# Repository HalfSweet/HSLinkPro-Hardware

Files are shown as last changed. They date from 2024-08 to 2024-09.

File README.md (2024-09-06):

# HSLinkPro

## 本仓库不再更新！！

新的参考设计: <https://github.com/cherry-embedded/CherryDAP/tree/master/projects/HSLink-Pro/hardware>

HSLink Pro是一款基于HPM5301系列MCU的调试器。最高SWD/JTAG通信速率可达80M，并且拥有一路USB转串口，并带有DTR与RTS的输出，方便某些串口下载的MCU应用。

HSLink Pro软件参考<https://github.com/cherry-embedded/CherryDAP>。

## KiCAD 版本

使用8.0以上版本的KiCAD打开。

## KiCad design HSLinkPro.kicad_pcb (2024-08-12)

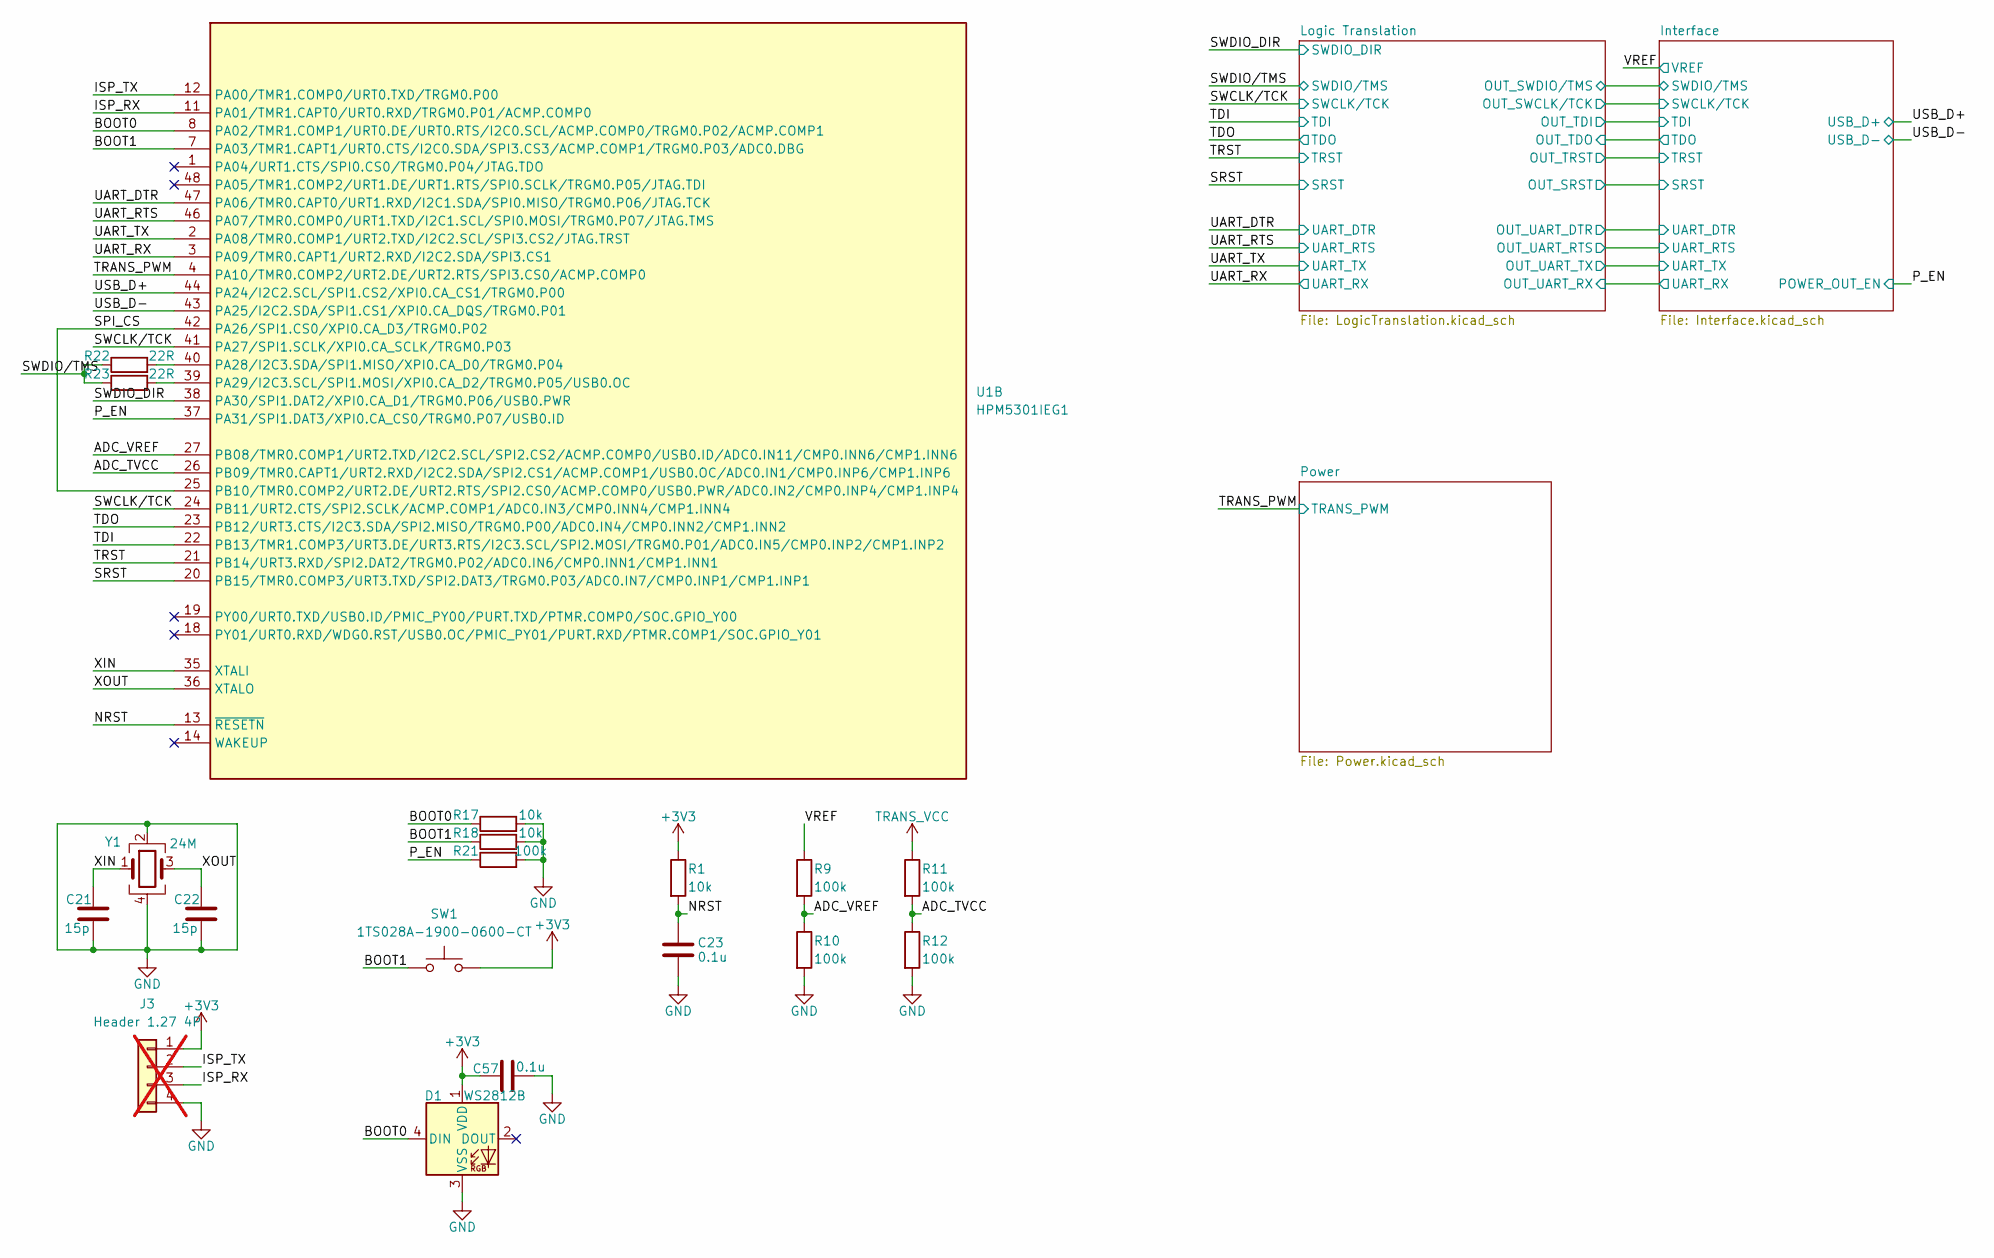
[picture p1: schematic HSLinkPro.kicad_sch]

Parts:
C21, C22: 15p; C_0402_1005Metric
C23, C57: 0.1u; C_0402_1005Metric
D1: WS2812B; LED_WS2812_0807
J3: Header 1.27 4P; PinHeader_1x04_P1.27mm_Vertical; not fitted
R1, R17, R18: 10k; R_0402_1005Metric
R9, R10, R11, R12, R21: 100k; R_0402_1005Metric
R22, R23: 22R; R_0402_1005Metric
SW1: 1TS028A-1900-0600-CT; SW-SMD_4P-L2.8-W1.9-P1.20-LS3.0_1TS028A
U1: HPM5301IEG1; QFN-48-1EP_6x6mm_P0.4mm_EP4.2x4.2mm
Y1: 24M; Crystal_SMD_2016-4Pin_2.0x1.6mm

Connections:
+3V3: C57.1, D1.1 (VDD), J3.1, R1.1, SW1.2; also elsewhere on the board
/ADC_TVCC: R11.2, R12.1, U1.26 (PB09/TMR0.CAPT1/URT2.RXD/I2C2.SDA/SPI2.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)
/ADC_VREF: R9.2, R10.1, U1.27 (PB08/TMR0.COMP1/URT2.TXD/I2C2.SCL/SPI2.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)
/BOOT0: D1.4 (DIN), R17.1, U1.8 (PA02/TMR1.COMP1/URT0.DE/URT0.RTS/I2C0.S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)
/BOOT1: R18.1, SW1.1, U1.7 (PA03/TMR1.CAPT1/URT0.CTS/I2C0.SDA/SPI3.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)
/ISP_RX: J3.3, U1.11 (PA01/TMR1.CAPT0/URT0.RXD/TRGM0.P01/ACMP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)
/ISP_TX: J3.2, U1.12 (PA00/TMR1.COMP0/URT0.TXD/TRGM0.P00)
/NRST: C23.1, R1.2, U1.13 (~RESETN)
/P_EN: R21.1, U1.37 (PA31/SPI1.DAT3/XPI0.CA_CS0/TRGM0.P07/US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); also elsewhere on the board
/SPI_CS: U1.25 (PB10/TMR0.COMP2/URT2.DE/URT2.RTS/SPI2.C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), U1.42 (PA26/SPI1.CS0/XPI0.CA_D3/TRGM0.P02)
/SRST: U1.20 (PB15/TMR0.COMP3/URT3.TXD/SPI2.DAT3/TRGM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); also elsewhere on the board
/SWCLK/TCK: U1.24 (PB11/URT2.CTS/SPI2.SCLK/ACMP.COMP1/ADC0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), U1.41 (PA27/SPI1.SCLK/XPI0.CA_SCLK/TRGM0.P03); also elsewhere on the board
/SWDIO_DIR: U1.38 (PA30/SPI1.DAT2/XPI0.CA_D1/TRGM0.P06/USB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); also elsewhere on the board
/SWDIO/TMS: R22.1, R23.1; also elsewhere on the board
/TDI: U1.22 (PB13/TMR1.COMP3/URT3.DE/URT3.RTS/I2C3.S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); also elsewhere on the board
/TDO: U1.23 (PB12/URT3.CTS/I2C3.SDA/SPI2.MISO/TRGM0.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); also elsewhere on the board
/TRANS_PWM: U1.4 (PA10/TMR0.COMP2/URT2.DE/URT2.RTS/SPI3.C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); also elsewhere on the board
/TRST: U1.21 (PB14/URT3.RXD/SPI2.DAT2/TRGM0.P02/ADC0.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); also elsewhere on the board
/UART_DTR: U1.47 (PA06/TMR0.CAPT0/URT1.RXD/I2C1.SDA/SPI0.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); also elsewhere on the board
/UART_RTS: U1.46 (PA07/TMR0.COMP0/URT1.TXD/I2C1.SCL/SPI0.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); also elsewhere on the board
/UART_RX: U1.3 (PA09/TMR0.CAPT1/URT2.RXD/I2C2.SDA/SPI3.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); also elsewhere on the board
/UART_TX: U1.2 (PA08/TMR0.COMP1/URT2.TXD/I2C2.SCL/SPI3.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); also elsewhere on the board
/USB_D+: U1.44 (PA24/I2C2.SCL/SPI1.CS2/XPI0.CA_CS1/TRGM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); also elsewhere on the board
/USB_D-: U1.43 (PA25/I2C2.SDA/SPI1.CS1/XPI0.CA_DQS/TRGM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); also elsewhere on the board
/VREF: R9.1; also elsewhere on the board
/XIN: C21.1, U1.35 (XTALI), Y1.1
/XOUT: C22.1, U1.36 (XTALO), Y1.3
GND: C21.2, C22.2, C23.2, C57.2, D1.3 (VSS), J3.4, R10.2, R12.2, R17.2, R18.2, R21.2, Y1.2, Y1.4; also elsewhere on the board
unnamed: R22.2, U1.40 (PA28/I2C3.SDA/SPI1.MISO/XPI0.CA_D0/TRGM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)
unnamed: R23.2, U1.39 (PA29/I2C3.SCL/SPI1.MOSI/XPI0.CA_D2/TRGM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)
TRANS_VCC: R11.1; also elsewhere on the board

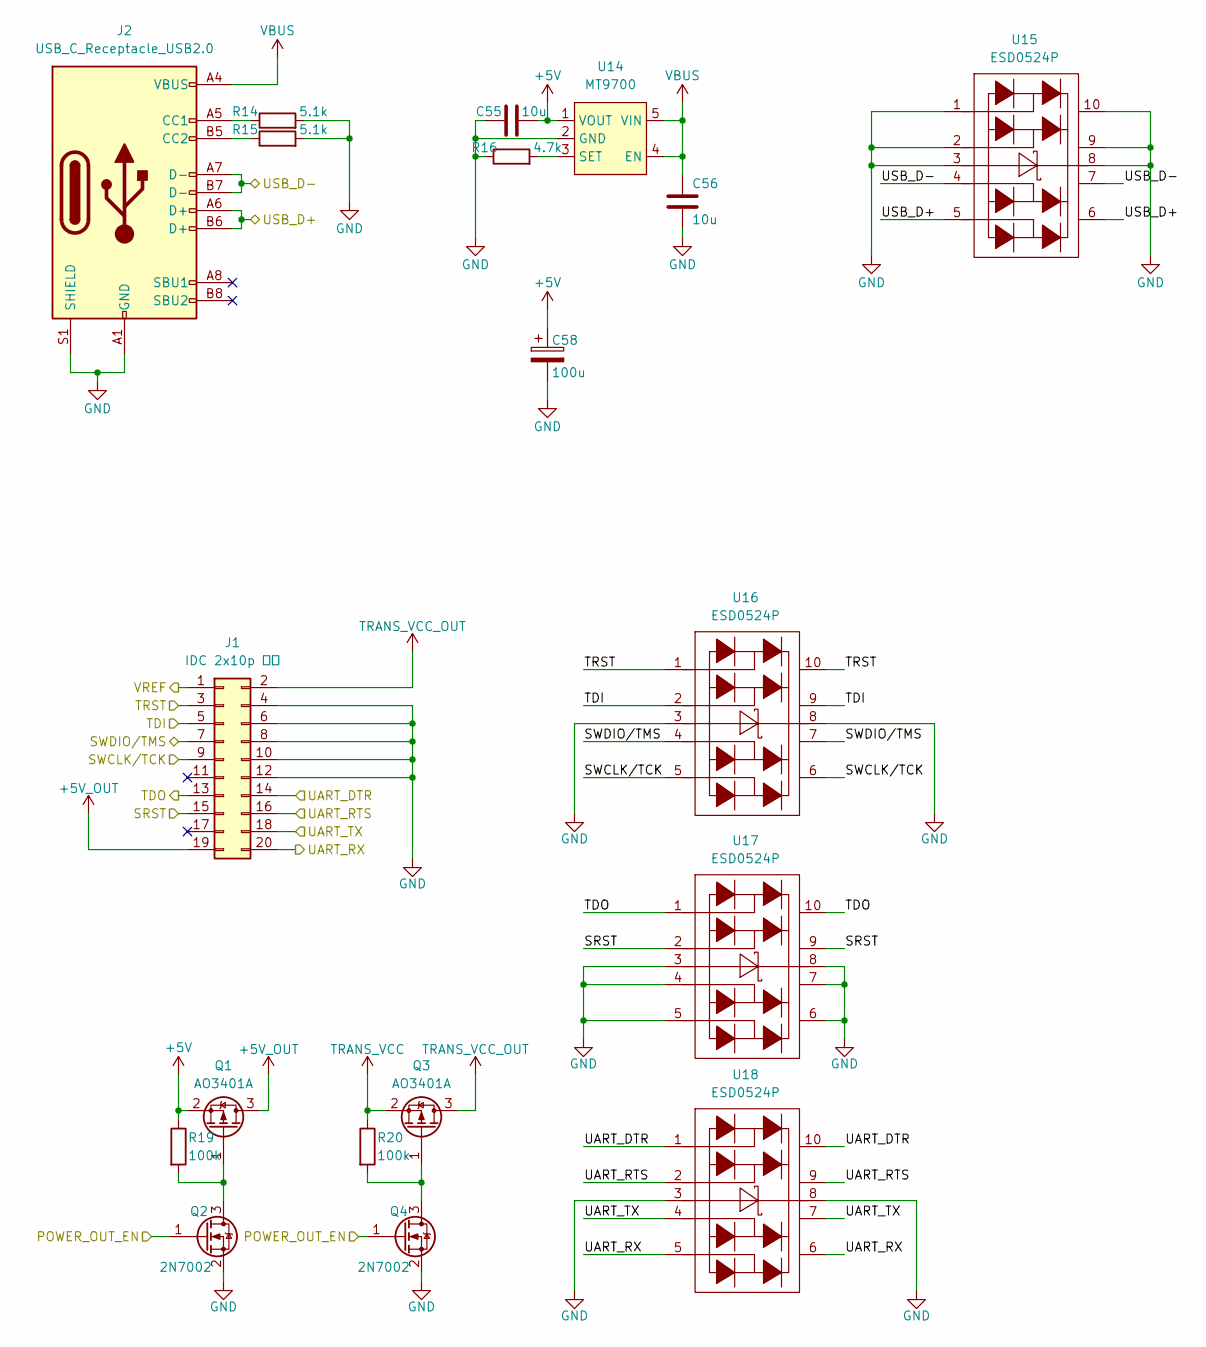
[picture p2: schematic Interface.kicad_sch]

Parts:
C55, C56: 10u; C_0603_1608Metric
C58: 100u; CP_EIA-3528-21_Kemet-B
J1: IDC 2x10p 夹板; Conn_02x10_IDC_SMD
J2: USB_C_Receptacle_USB2.0; USB-C-SMD_CX90M-16P
Q1, Q3: AO3401A; SOT-23
Q2, Q4: 2N7002; SOT-323_SC-70
R14, R15: 5.1k; R_0402_1005Metric
R16: 4.7k; R_0402_1005Metric
R19, R20: 100k; R_0402_1005Metric
U14: MT9700; SOT-23-5
U15, U16, U17, U18: ESD0524P; DFN-10_L2.5-W1.0-P0.50-BL-A

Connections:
+5V: C55.2, C58.1, Q1.2 (S), R19.1, U14.1 (VOUT); also elsewhere on the board
+5V_OUT: J1.19, Q1.3 (D)
/Interface /<NO NET>: J1.5, U16.2, U16.9; also elsewhere on the board
/Interface /SRST: J1.15, U17.2, U17.9; also elsewhere on the board
/Interface /SWCLK/TCK: J1.9, U16.5, U16.6; also elsewhere on the board
/Interface /SWDIO/TMS: J1.7, U16.4, U16.7; also elsewhere on the board
/Interface /TDO: J1.13, U17.1, U17.10; also elsewhere on the board
/Interface /TRST: J1.3, U16.1, U16.10; also elsewhere on the board
/Interface /UART_DTR: J1.14, U18.1, U18.10; also elsewhere on the board
/Interface /UART_RTS: J1.16, U18.2, U18.9; also elsewhere on the board
/Interface /UART_RX: J1.20, U18.5, U18.6; also elsewhere on the board
/Interface /UART_TX: J1.18, U18.4, U18.7; also elsewhere on the board
/P_EN: Q2.1 (G), Q4.1 (G); also elsewhere on the board
/USB_D+: J2.A6 (D+), J2.B6 (D+), U15.5, U15.6; also elsewhere on the board
/USB_D-: J2.A7 (D-), J2.B7 (D-), U15.4, U15.7; also elsewhere on the board
/VREF: J1.1; also elsewhere on the board
GND: C55.1, C56.2, C58.2, J1.4, J1.6, J1.8, J1.10, J1.12, J2.A1 (GND), J2.A12 (GND), J2.B1 (GND), J2.B12 (GND), J2.S1 (SHIELD), Q2.2 (S), Q4.2 (S), R14.2, R15.2, R16.1, U14.2 (GND), U15.1, U15.2, U15.3, U15.8, U15.9, U15.10, U16.3, U16.8, U17.3, U17.4, U17.5, U17.6, U17.7, U17.8, U18.3, U18.8; also elsewhere on the board
unnamed: J2.A5 (CC1), R14.1
unnamed: J2.B5 (CC2), R15.1
unnamed: Q1.1 (G), Q2.3 (D), R19.2
unnamed: Q3.1 (G), Q4.3 (D), R20.2
unnamed: R16.2, U14.3 (SET)
TRANS_VCC: Q3.2 (S), R20.1; also elsewhere on the board
TRANS_VCC_OUT: J1.2, Q3.3 (D)
VBUS: C56.1, J2.A4 (VBUS), J2.A9 (VBUS), J2.B4 (VBUS), J2.B9 (VBUS), U14.4 (EN), U14.5 (VIN)

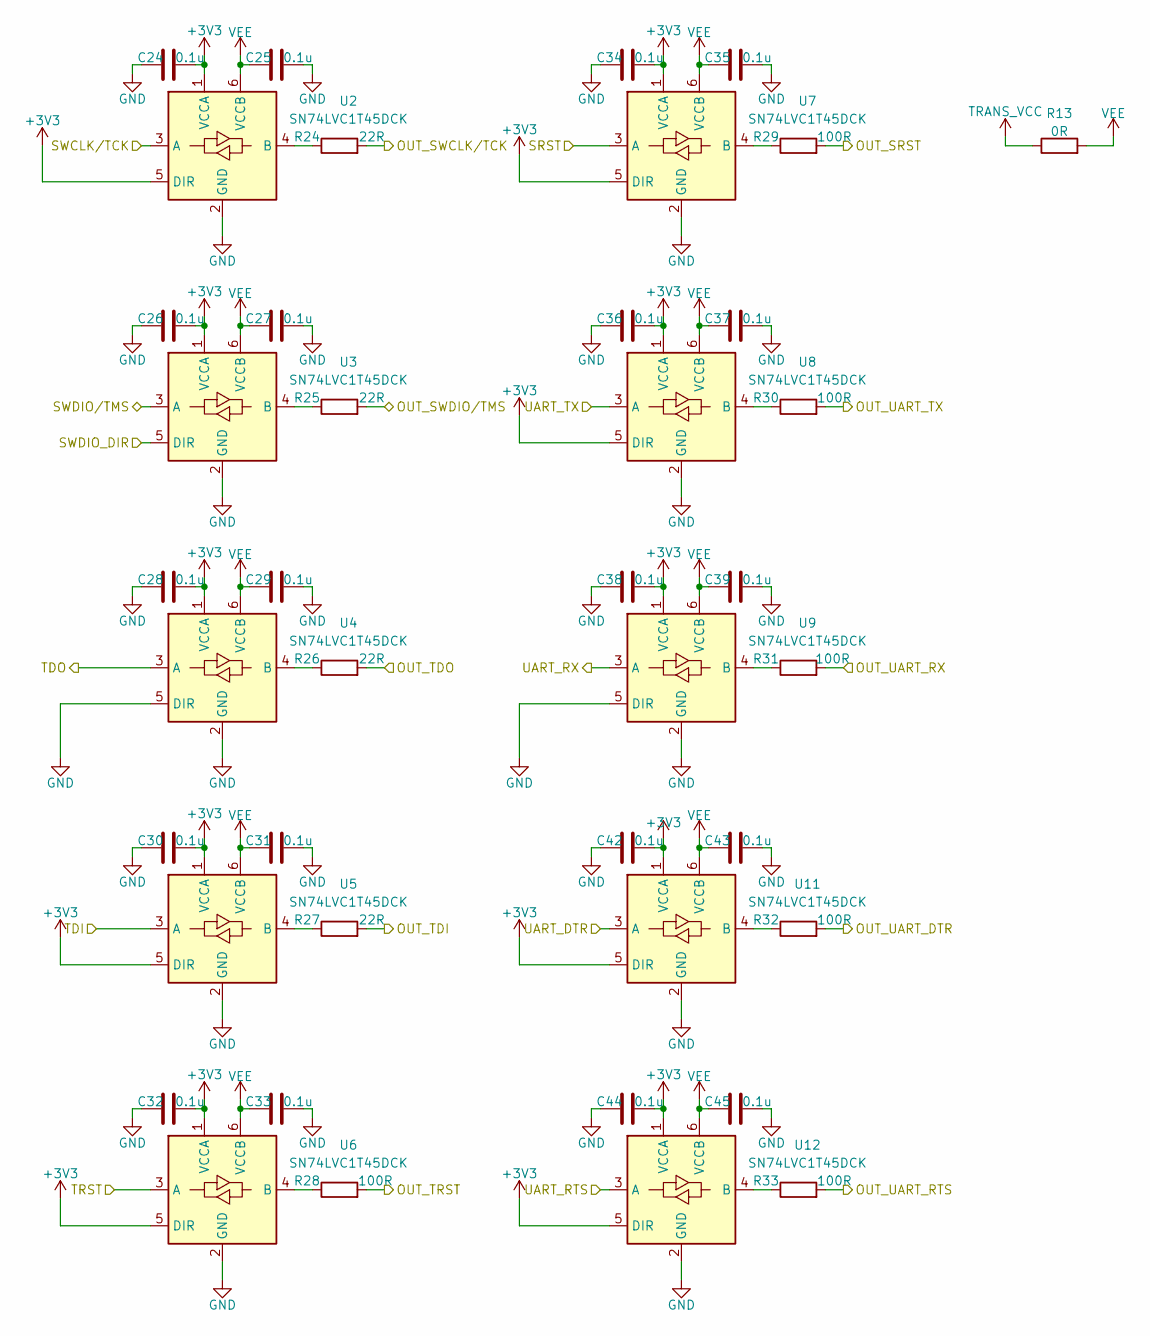
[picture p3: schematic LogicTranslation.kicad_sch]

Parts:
C24, C25, C26, C27, C28, C29, C30, C31, C32, C33, C34, C35, C36, C37, C38, C39, C42, C43, C44, C45: 0.1u; C_0402_1005Metric
R13: 0R; R_0603_1608Metric
R24, R25, R26, R27: 22R; R_0402_1005Metric
R28, R29, R30, R31, R32, R33: 100R; R_0402_1005Metric
U2, U3, U4, U5, U6, U7, U8, U9, U11, U12: SN74LVC1T45DCK; SOT-363_SC-70-6

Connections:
+3V3: C24.2, C26.2, C28.2, C30.2, C32.2, C34.2, C36.2, C38.2, C42.2, C44.2, U2.1 (VCCA), U2.5 (DIR), U3.1 (VCCA), U4.1 (VCCA), U5.1 (VCCA), U5.5 (DIR), U6.1 (VCCA), U6.5 (DIR), U7.1 (VCCA), U7.5 (DIR), U8.1 (VCCA), U8.5 (DIR), U9.1 (VCCA), U11.1 (VCCA), U11.5 (DIR), U12.1 (VCCA), U12.5 (DIR); also elsewhere on the board
/Interface /<NO NET>: R27.2; also elsewhere on the board
/Interface /SRST: R29.2; also elsewhere on the board
/Interface /SWCLK/TCK: R24.2; also elsewhere on the board
/Interface /SWDIO/TMS: R25.2; also elsewhere on the board
/Interface /TDO: R26.2; also elsewhere on the board
/Interface /TRST: R28.2; also elsewhere on the board
/Interface /UART_DTR: R32.2; also elsewhere on the board
/Interface /UART_RTS: R33.2; also elsewhere on the board
/Interface /UART_RX: R31.2; also elsewhere on the board
/Interface /UART_TX: R30.2; also elsewhere on the board
/SRST: U7.3 (A); also elsewhere on the board
/SWCLK/TCK: U2.3 (A); also elsewhere on the board
/SWDIO_DIR: U3.5 (DIR); also elsewhere on the board
/SWDIO/TMS: U3.3 (A); also elsewhere on the board
/TDI: U5.3 (A); also elsewhere on the board
/TDO: U4.3 (A); also elsewhere on the board
/TRST: U6.3 (A); also elsewhere on the board
/UART_DTR: U11.3 (A); also elsewhere on the board
/UART_RTS: U12.3 (A); also elsewhere on the board
/UART_RX: U9.3 (A); also elsewhere on the board
/UART_TX: U8.3 (A); also elsewhere on the board
GND: C24.1, C25.2, C26.1, C27.2, C28.1, C29.2, C30.1, C31.2, C32.1, C33.2, C34.1, C35.2, C36.1, C37.2, C38.1, C39.2, C42.1, C43.2, C44.1, C45.2, U2.2 (GND), U3.2 (GND), U4.2 (GND), U4.5 (DIR), U5.2 (GND), U6.2 (GND), U7.2 (GND), U8.2 (GND), U9.2 (GND), U9.5 (DIR), U11.2 (GND), U12.2 (GND); also elsewhere on the board
unnamed: R24.1, U2.4 (B)
unnamed: R25.1, U3.4 (B)
unnamed: R26.1, U4.4 (B)
unnamed: R27.1, U5.4 (B)
unnamed: R28.1, U6.4 (B)
unnamed: R29.1, U7.4 (B)
unnamed: R30.1, U8.4 (B)
unnamed: R31.1, U9.4 (B)
unnamed: R32.1, U11.4 (B)
unnamed: R33.1, U12.4 (B)
TRANS_VCC: R13.1; also elsewhere on the board
VEE: C25.1, C27.1, C29.1, C31.1, C33.1, C35.1, C37.1, C39.1, C43.1, C45.1, R13.2, U2.6 (VCCB), U3.6 (VCCB), U4.6 (VCCB), U5.6 (VCCB), U6.6 (VCCB), U7.6 (VCCB), U8.6 (VCCB), U9.6 (VCCB), U11.6 (VCCB), U12.6 (VCCB)

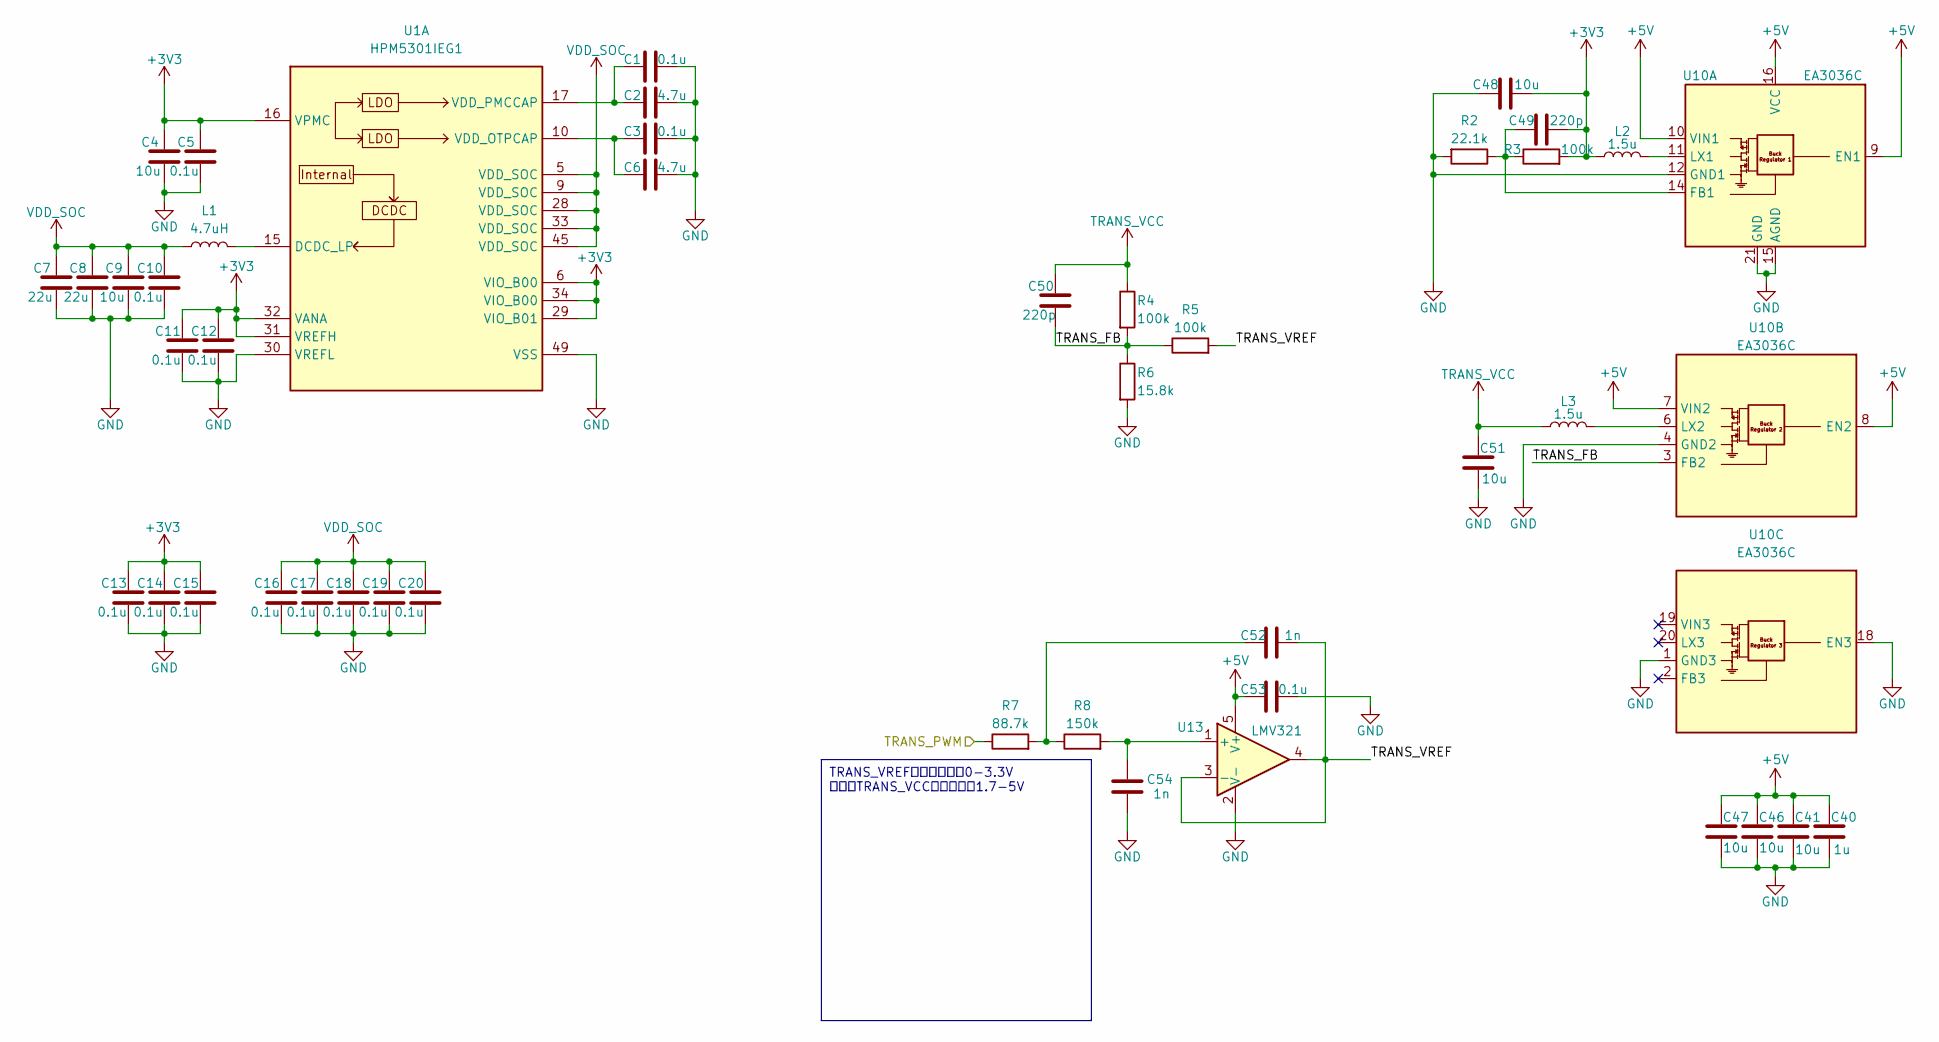
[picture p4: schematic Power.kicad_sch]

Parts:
C1, C3, C5, C10, C11, C12, C13, C14, C15, C16, C17, C18, C19, C20, C53: 0.1u; C_0402_1005Metric
C2, C6: 4.7u; C_0402_1005Metric
C4, C9, C48: 10u; C_0402_1005Metric
C7, C8: 22u; C_0402_1005Metric
C40: 1u; C_0402_1005Metric
C41, C46, C47, C51: 10u; C_0603_1608Metric
C49, C50: 220p; C_0402_1005Metric
C52, C54: 1n; C_0402_1005Metric
L1: 4.7uH; L_1008_2520Metric
L2, L3: 1.5u; L_1008_2520Metric
R2: 22.1k; R_0402_1005Metric
R3, R4, R5: 100k; R_0402_1005Metric
R6: 15.8k; R_0402_1005Metric
R7: 88.7k; R_0402_1005Metric
R8: 150k; R_0402_1005Metric
U1: HPM5301IEG1; QFN-48-1EP_6x6mm_P0.4mm_EP4.2x4.2mm
U10: EA3036C; QFN-20-1EP_3x3mm_P0.4mm_EP1.65x1.65mm
U13: LMV321; SOT-353_SC-70-5

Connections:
+3V3: C4.1, C5.1, C11.1, C12.1, C13.1, C14.1, C15.1, C48.2, C49.2, L2.1, R3.2, U1.6 (VIO_B00), U1.16 (VPMC), U1.29 (VIO_B01), U1.31 (VREFH), U1.32 (VANA), U1.34 (VIO_B00); also elsewhere on the board
+5V: C40.1, C41.1, C46.1, C47.1, C53.1, U10.7 (VIN2), U10.8 (EN2), U10.9 (EN1), U10.10 (VIN1), U10.16 (VCC), U13.5 (V+); also elsewhere on the board
/Power/TRANS_FB: C50.2, R4.2, R5.1, R6.1, U10.3 (FB2)
/Power/TRANS_VREF: C52.2, R5.2, U13.3 (-), U13.4
/TRANS_PWM: R7.1; also elsewhere on the board
GND: C1.2, C2.2, C3.2, C4.2, C5.2, C6.2, C7.2, C8.2, C9.2, C10.2, C11.2, C12.2, C13.2, C14.2, C15.2, C16.2, C17.2, C18.2, C19.2, C20.2, C40.2, C41.2, C46.2, C47.2, C48.1, C51.2, C53.2, C54.2, R2.2, R6.2, U1.30 (VREFL), U1.49 (VSS), U10.1 (GND3), U10.4 (GND2), U10.5 (GND2), U10.12 (GND1), U10.13 (GND1), U10.15 (AGND), U10.17 (AGND), U10.18 (EN3), U10.21 (GND), U13.2 (V-); also elsewhere on the board
unnamed: C52.1, R7.2, R8.1
unnamed: L1.2, U1.15 (DCDC_LP)
unnamed: C3.1, C6.1, U1.10 (VDD_OTPCAP)
unnamed: C1.1, C2.1, U1.17 (VDD_PMCCAP)
unnamed: C49.1, R2.1, R3.1, U10.14 (FB1)
unnamed: L2.2, U10.11 (LX1)
unnamed: L3.2, U10.6 (LX2)
unnamed: C54.1, R8.2, U13.1 (+)
TRANS_VCC: C50.1, C51.1, L3.1, R4.1; also elsewhere on the board
VDD_SOC: C7.1, C8.1, C9.1, C10.1, C16.1, C17.1, C18.1, C19.1, C20.1, L1.1, U1.5 (VDD_SOC), U1.9 (VDD_SOC), U1.28 (VDD_SOC), U1.33 (VDD_SOC), U1.45 (VDD_SOC)

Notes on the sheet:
TRANS_VREF的电压范围为0-3.3V 映射到TRANS_VCC上的电压为1.7-5V

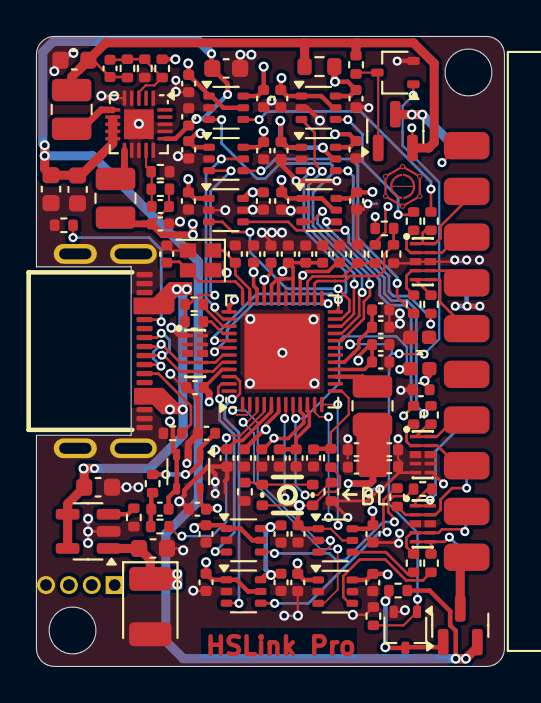
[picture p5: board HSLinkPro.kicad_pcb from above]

Board: 4 copper layers, 26.0 x 35.0 mm, 122 parts (0 on the bottom side), 72 nets.

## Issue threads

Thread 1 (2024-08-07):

是否有计划适配 https://github.com/probe-rs/probe-rs

taotieren, 2024-08-07:
是否有计划适配 https://github.com/probe-rs/probe-rs

solosky, 2024-08-07:
这只是一个CMISS-DAP兼容的调试器，probe-rs本来就支持。

taotieren, 2024-08-07:
hs-probe-firmware 支持 USB 2.0 HS 是否会适配 https://github.com/probe-rs/hs-probe-firmware

HalfSweet, 2024-08-07:
本来就原生支持probe-rs
probe-rs可以理解为gdb sever，cmsis-dap是debugger的通信兼容层；hslink是一个实现了cmsis-dap协议的硬件，hs-probe同样是一个实现了cmsis-dap的硬件；CherryDAP是一个实现cmsis-dap的软件框架。这几个概念希望能理解一下。

Closed 2024-08-07.

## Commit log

2024-07-11 add: 添加原理图和PCB
    [HSLinkPro.kicad_pcb, HSLinkPro.kicad_sch, Interface.kicad_sch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]
2024-07-11 update: 更新gitignore
2024-07-19 update: 添加一些丝印
    [HSLinkPro.kicad_pcb]
2024-07-28 update: 更新设计
    [HSLinkPro.kicad_pcb, HSLinkPro.kicad_sch, Interface.kicad_sch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]
2024-08-05 update: 1.1.0设计
    [HSLinkPro.kicad_pcb, HSLinkPro.kicad_sch, Power.kicad_sch]
